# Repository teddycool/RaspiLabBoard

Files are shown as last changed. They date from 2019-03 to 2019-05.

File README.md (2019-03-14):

# RaspiLabBoard
A circuit board and a python lib to make it easier to demonstarte and try things out on a RasberryPi. The board was made to try out AWS greengrass with a raspberry pi as a device with CAN capabillities but can of course be used for other purposes as well. 

The board is a raspberry pi hat that fits in to the IO.

The circuit-board, ordererd from aisler.net, see: https://aisler.net/p/SKYVGCNC 

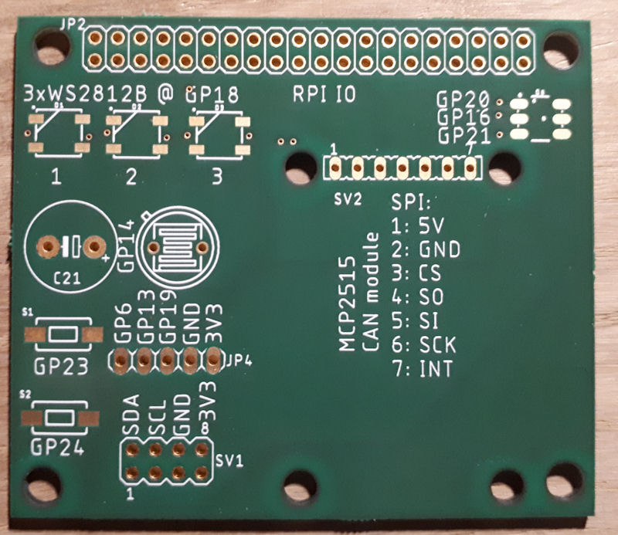
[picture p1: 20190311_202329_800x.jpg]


Assembled circuitboard with a pi in the background. Ready to use :-)

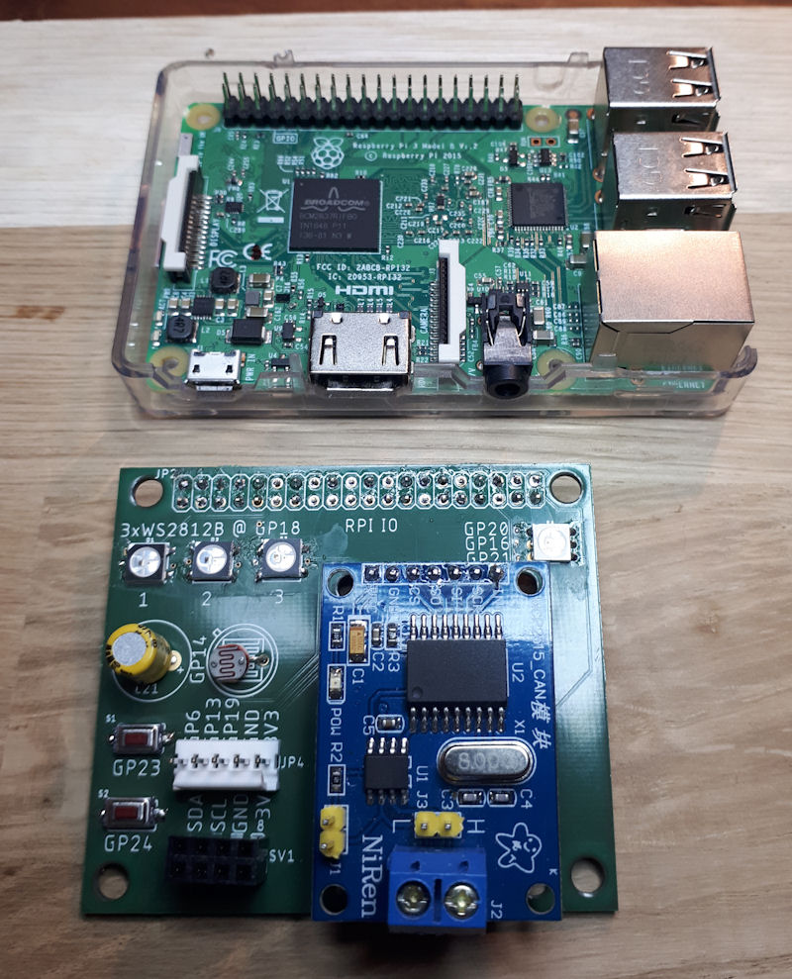
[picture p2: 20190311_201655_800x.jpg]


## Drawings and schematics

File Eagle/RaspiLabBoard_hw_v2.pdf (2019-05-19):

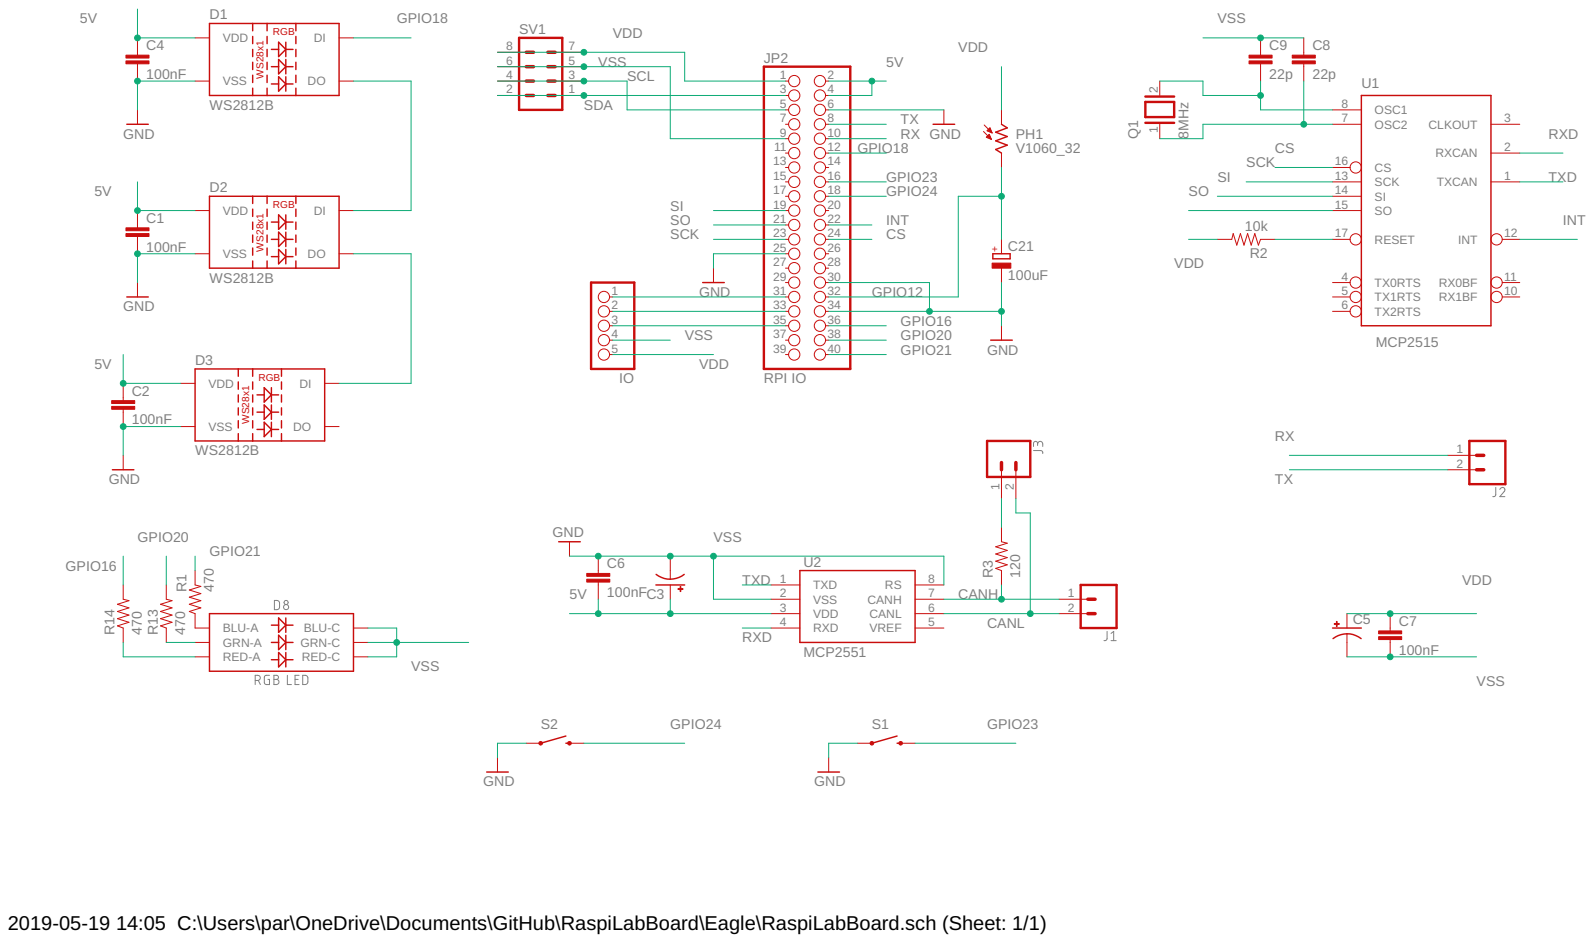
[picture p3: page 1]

2019-05-19 14:05 C:\Users\par\OneDrive\Documents\GitHub\RaspiLabBoard\Eagle\RaspiLabBoard.sch (Sheet: 1/1)

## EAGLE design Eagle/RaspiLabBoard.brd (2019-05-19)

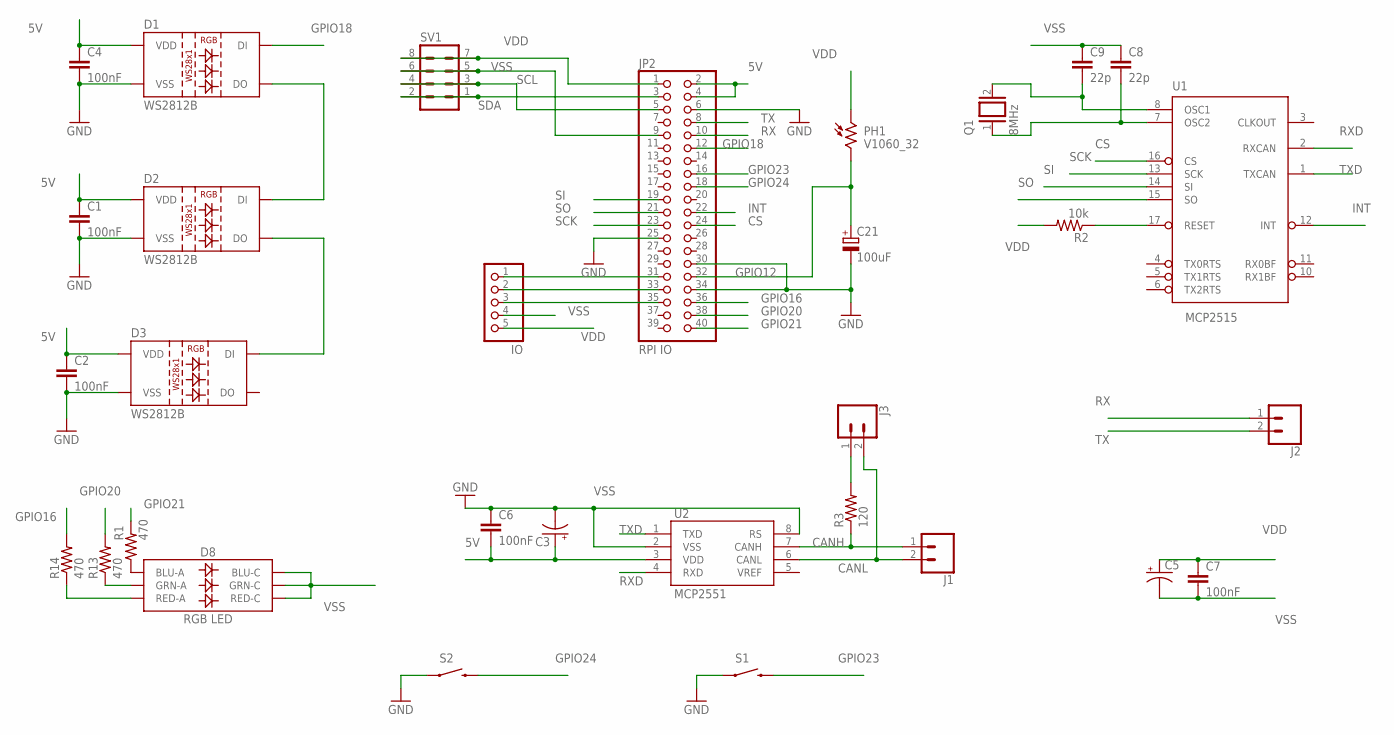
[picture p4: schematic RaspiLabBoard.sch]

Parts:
C1, C2, C4, C6, C7: 100nF; 0805
C3, C5: CPOL-USE2-5; E2-5
C8, C9: 22p; 0805
C21: 100uF; E5-10,5
D1, D2, D3: WS2812B
D8: RGB LED; LED-TRICOLOR-5050
J1, J2, J3: CONN_02; 1X02
JP2: RPI IO; 2X20
JP4: IO; 1X05
PH1: V1060_32; TO-5_V10
Q1: 8MHz; QS
R1, R13, R14: 470; 0805
R2: 10k; 0805
R3: 120; 0805
S1, S2: RESET; TACTILE-SWITCH-1101NE
SV1: MA04-2
U1: MCP2515; SO18W
U2: MCP2551; SO08

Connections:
5V: C1.1, C2.1, C3.+, C4.1, C6.2, D1.1 (VDD), D2.1 (VDD), D3.1 (VDD), JP2.2, JP2.4, U2.3 (VDD)
CANH: J1.1, R3.1, U2.7 (CANH)
CANL: J1.2, J3.2, U2.6 (CANL)
CS: JP2.24, U1.16 (CS)
GPIO6: JP2.31, JP4.1
GPIO12: C21.+, JP2.32, PH1.2
GPIO13: JP2.33, JP4.2
GPIO16: JP2.36, R14.2
GPIO18: D1.4 (DI), JP2.12
GPIO19: JP2.35, JP4.3
GPIO20: JP2.38, R13.2
GPIO21: JP2.40, R1.2
GPIO23: JP2.16, S1.2
GPIO24: JP2.18, S2.2
INT: JP2.22, U1.12 (INT)
unnamed: D2.2 (DO), D3.4 (DI)
unnamed: D8.1 (GRN-A), R13.1
unnamed: D8.3 (BLU-A), R1.1
unnamed: R2.1, U1.17 (RESET)
unnamed: C9.2, Q1.2, U1.8 (OSC1)
unnamed: D8.2 (RED-A), R14.1
unnamed: C8.2, Q1.1, U1.7 (OSC2)
unnamed: J3.1, R3.2
unnamed: D1.2 (DO), D2.4 (DI)
RX: J2.1, JP2.10
RXD: U1.2 (RXCAN), U2.4 (RXD)
SCK: JP2.23, U1.13 (SCK)
SCL: JP2.5, SV1.3, SV1.4
SDA: JP2.3, SV1.1, SV1.2
SI: JP2.19, U1.14 (SI)
SO: JP2.21, U1.15 (SO)
TX: J2.2, JP2.8
TXD: U1.1 (TXCAN), U2.1 (TXD)
VDD: C5.+, C7.1, JP2.1, JP4.5, PH1.1, R2.2, SV1.7, SV1.8, U1.18 (VDD)
VSS: C1.2, C2.2, C3.-, C4.2, C5.-, C6.1, C7.2, C8.1, C9.1, C21.-, D1.3 (VSS), D2.3 (VSS), D3.3 (VSS), D8.4 (BLU-C), D8.5 (RED-C), D8.6 (GRN-C), JP2.6, JP2.9, JP2.25, JP2.30, JP2.34, JP4.4, S1.1, S2.1, SV1.5, SV1.6, U1.9 (VSS), U2.2 (VSS), U2.8 (RS)

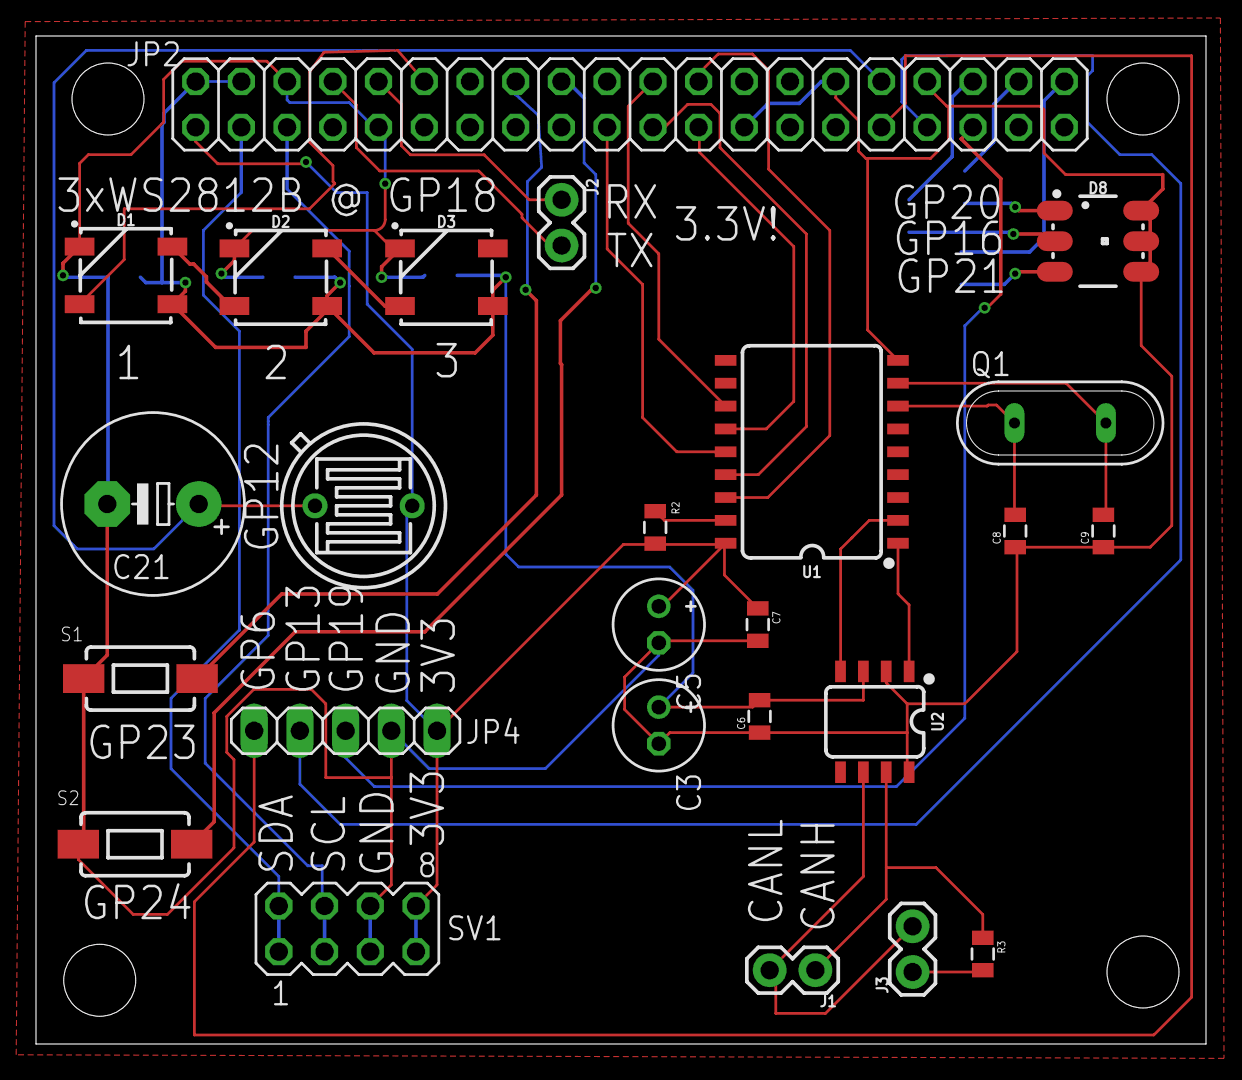
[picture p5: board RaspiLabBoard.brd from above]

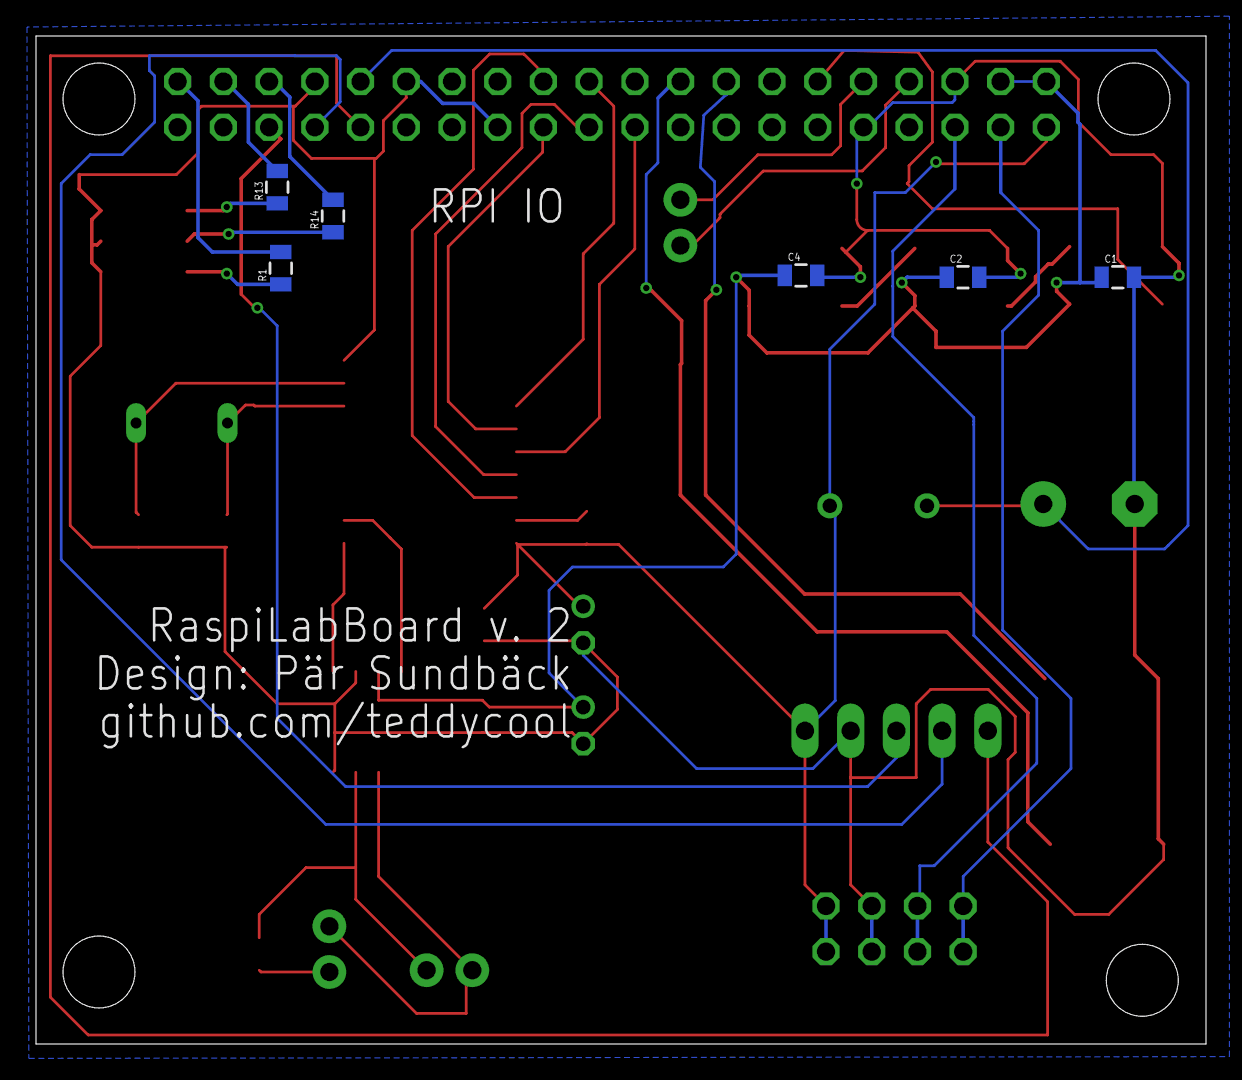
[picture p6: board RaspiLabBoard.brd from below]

Board: 2 copper layers, 65.0 x 56.0 mm, 31 parts (6 on the bottom side), 35 nets.

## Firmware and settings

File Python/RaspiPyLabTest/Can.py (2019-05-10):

#Simple class using CAN interface MCP2515 on SPI bus
#https://python-can.readthedocs.io/en/stable/index.html
#https://harrisonsand.com/can-on-the-raspberry-pi/
#pip install python-can


# 3073.000799 1  18FF3E30x       Rx   d 8 FF FF FF FF FF FF FF FF  Length = 0 BitCount = 0 ID = 419380784x
# 3073.001423 1  CFF7427x        Rx   d 8 FC FF F4 00 3F FF FF FF  Length = 0 BitCount = 0 ID = 218068007x
# 3073.001458 2  CFF3127x        Rx   d 8 00 C0 00 C0 FF FF FF FF  Length = 0 BitCount = 0 ID = 218050855x
# 3073.001488 6  4F0090Bx        Rx   d 8 FF FF FF 8F 7D D7 7D 7E  Length = 0 BitCount = 0 ID = 82839819x
# 3073.001558 4  18FF3B27x       Rx   d 8 CC CC CC FF CC FF FF FF  Length = 0 BitCount = 0 ID = 419380007x
# 3073.001705 1  CF02F11x        Rx   d 8 F1 FF FA FF FF FF FF FF  Length = 0 BitCount = 0 ID = 217067281x


import sys
sys.path.append('/usr/local/lib/python2.7/dist-packages')
sys.path.append('/usr/local/lib/python2.7/sqlite3')



import can


class Can(object):
    def __init__(self,):
        self._bus = can.interface.Bus(bustype='socketcan', channel='can0', bitrate=500000)
        #TBD...



    def ReadMsg(self,bus):
        for msg in bus:
            print(msg)



    def SendMsg(self, msg):
        try:
            self._bus.send(msg)
            print("Message sent on {}".format(self._bus.channel_info))
        except can.CanError:
            print("Message NOT sent")





if __name__ == '__main__':
    import RPi.GPIO as GPIO
    GPIO.setmode(GPIO.BCM)
    myCan =Can()
    msg = can.Message(arbitration_id=0xc0ffee,
                      data=[0, 25, 0, 1, 3, 1, 4, 1],
                      is_extended_id=True)

    myCan.SendMsg(msg)

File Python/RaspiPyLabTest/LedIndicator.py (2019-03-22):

__author__ = 'teddycool'
import time

class LedIndicator(object):
    def __init__(self, GPIO, controlpin):
        self._gpio = GPIO
        self._pin = controlpin
        self._gpio.setup(self._pin,self._gpio.OUT, initial=0)
        self._lastActivate = time.time()
        print "LedIndicator object created for IO: " + str(self._pin)

    def activate(self, on=True):
        if on:
            print "LedIndicator object activated for IO: " + str(self._pin)
            self._lastActivate = time.time()
        self._gpio.output(self._pin, on)


    def __del__(self):
        self.activate(False)
        print "LedIndicator object deactivated and deleted for IO: " + str(self._pin)


if __name__ == '__main__':
    print "Testcode for LedIndicators"
    import RPi.GPIO as GPIO
    GPIO.setmode(GPIO.BCM)
    led1 = LedIndicator(GPIO, 20)
    led2 = LedIndicator(GPIO, 16)
    led3 = LedIndicator(GPIO, 21)

    led1.activate(True)
    time.sleep(1)
    led2.activate(True)
    time.sleep(5)
    led3.activate(True)
    time.sleep(5)
    led1.activate(False)
    time.sleep(2)
    led2.activate(False)
    time.sleep(2)
    led3.activate(False)
    GPIO.cleanup()

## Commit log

2019-03-14 First commit
    First commit of this repo. The hardware and first version of test-code in python
    [RaspiLabBoard.brd, RaspiLabBoard.sch]
2019-05-19 Hardware version 2
    As ordered from Aisler.net 20190519
    [RaspiLabBoard.brd, RaspiLabBoard.sch]
2019-05-19 fixing pdf and history
    [RaspiLabBoard_old.sch]

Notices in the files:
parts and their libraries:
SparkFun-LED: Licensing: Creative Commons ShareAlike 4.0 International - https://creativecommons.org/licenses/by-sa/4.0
